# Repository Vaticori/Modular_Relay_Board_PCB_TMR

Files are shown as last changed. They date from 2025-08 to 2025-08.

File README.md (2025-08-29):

# Modular Relay Board TMR
A 4 channel relay board made for the Toronto Metropolitan Robotics team for higher voltage inputs to be switched using the onboard Teensy 4.1 MCU. 
I have linked the 3D model below, and a high resolution pdf of the schematic can be found in the repository. 

# [View Interactive 3D Model of my PCB!](https://skfb.ly/pACNG)
 
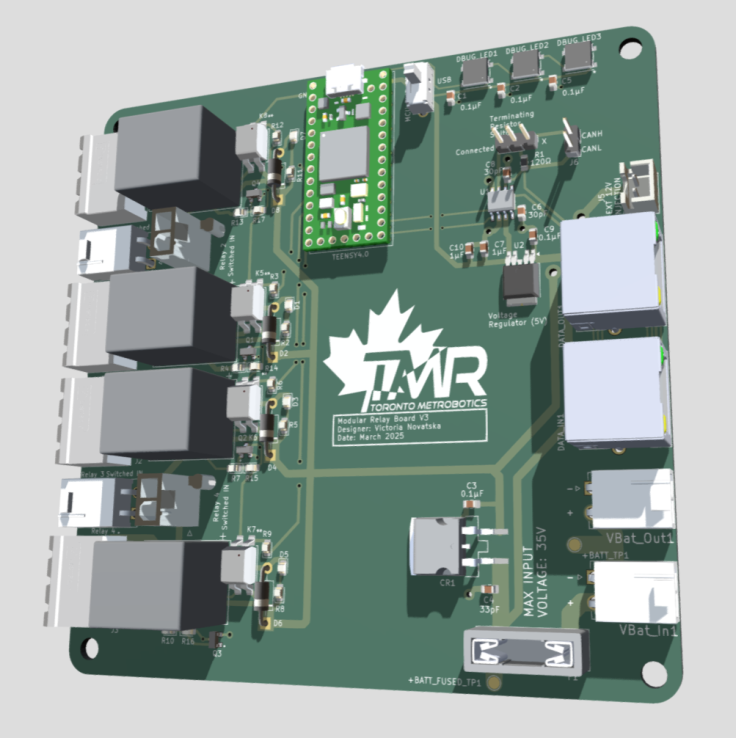
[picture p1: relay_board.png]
Relay Board


## Schematic 
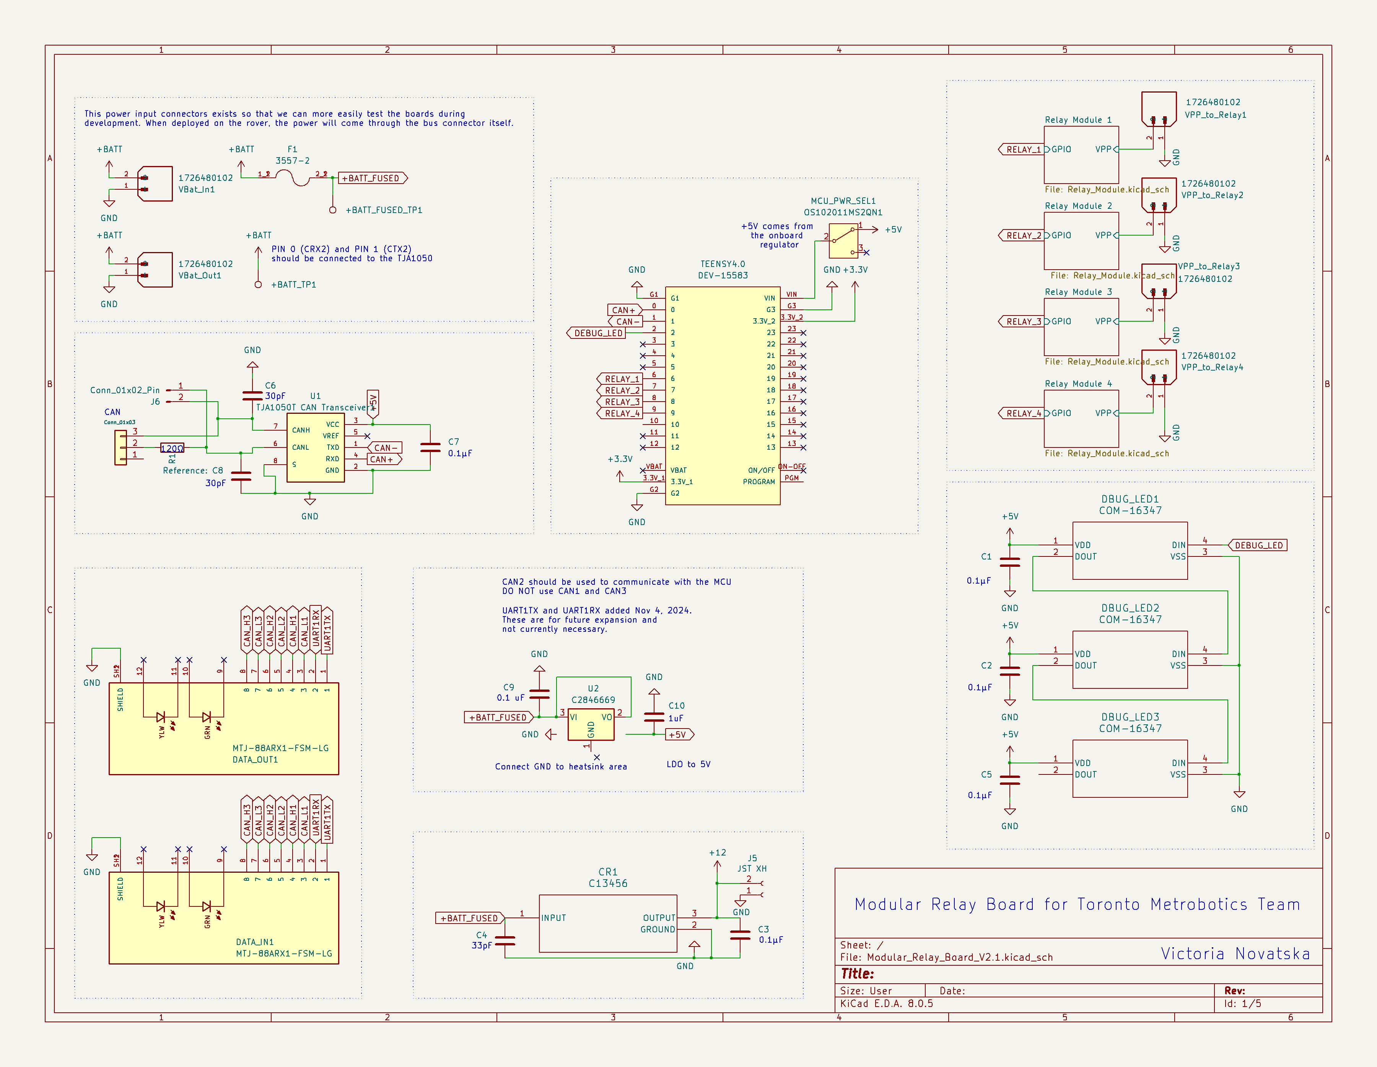
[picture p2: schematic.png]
Schematic


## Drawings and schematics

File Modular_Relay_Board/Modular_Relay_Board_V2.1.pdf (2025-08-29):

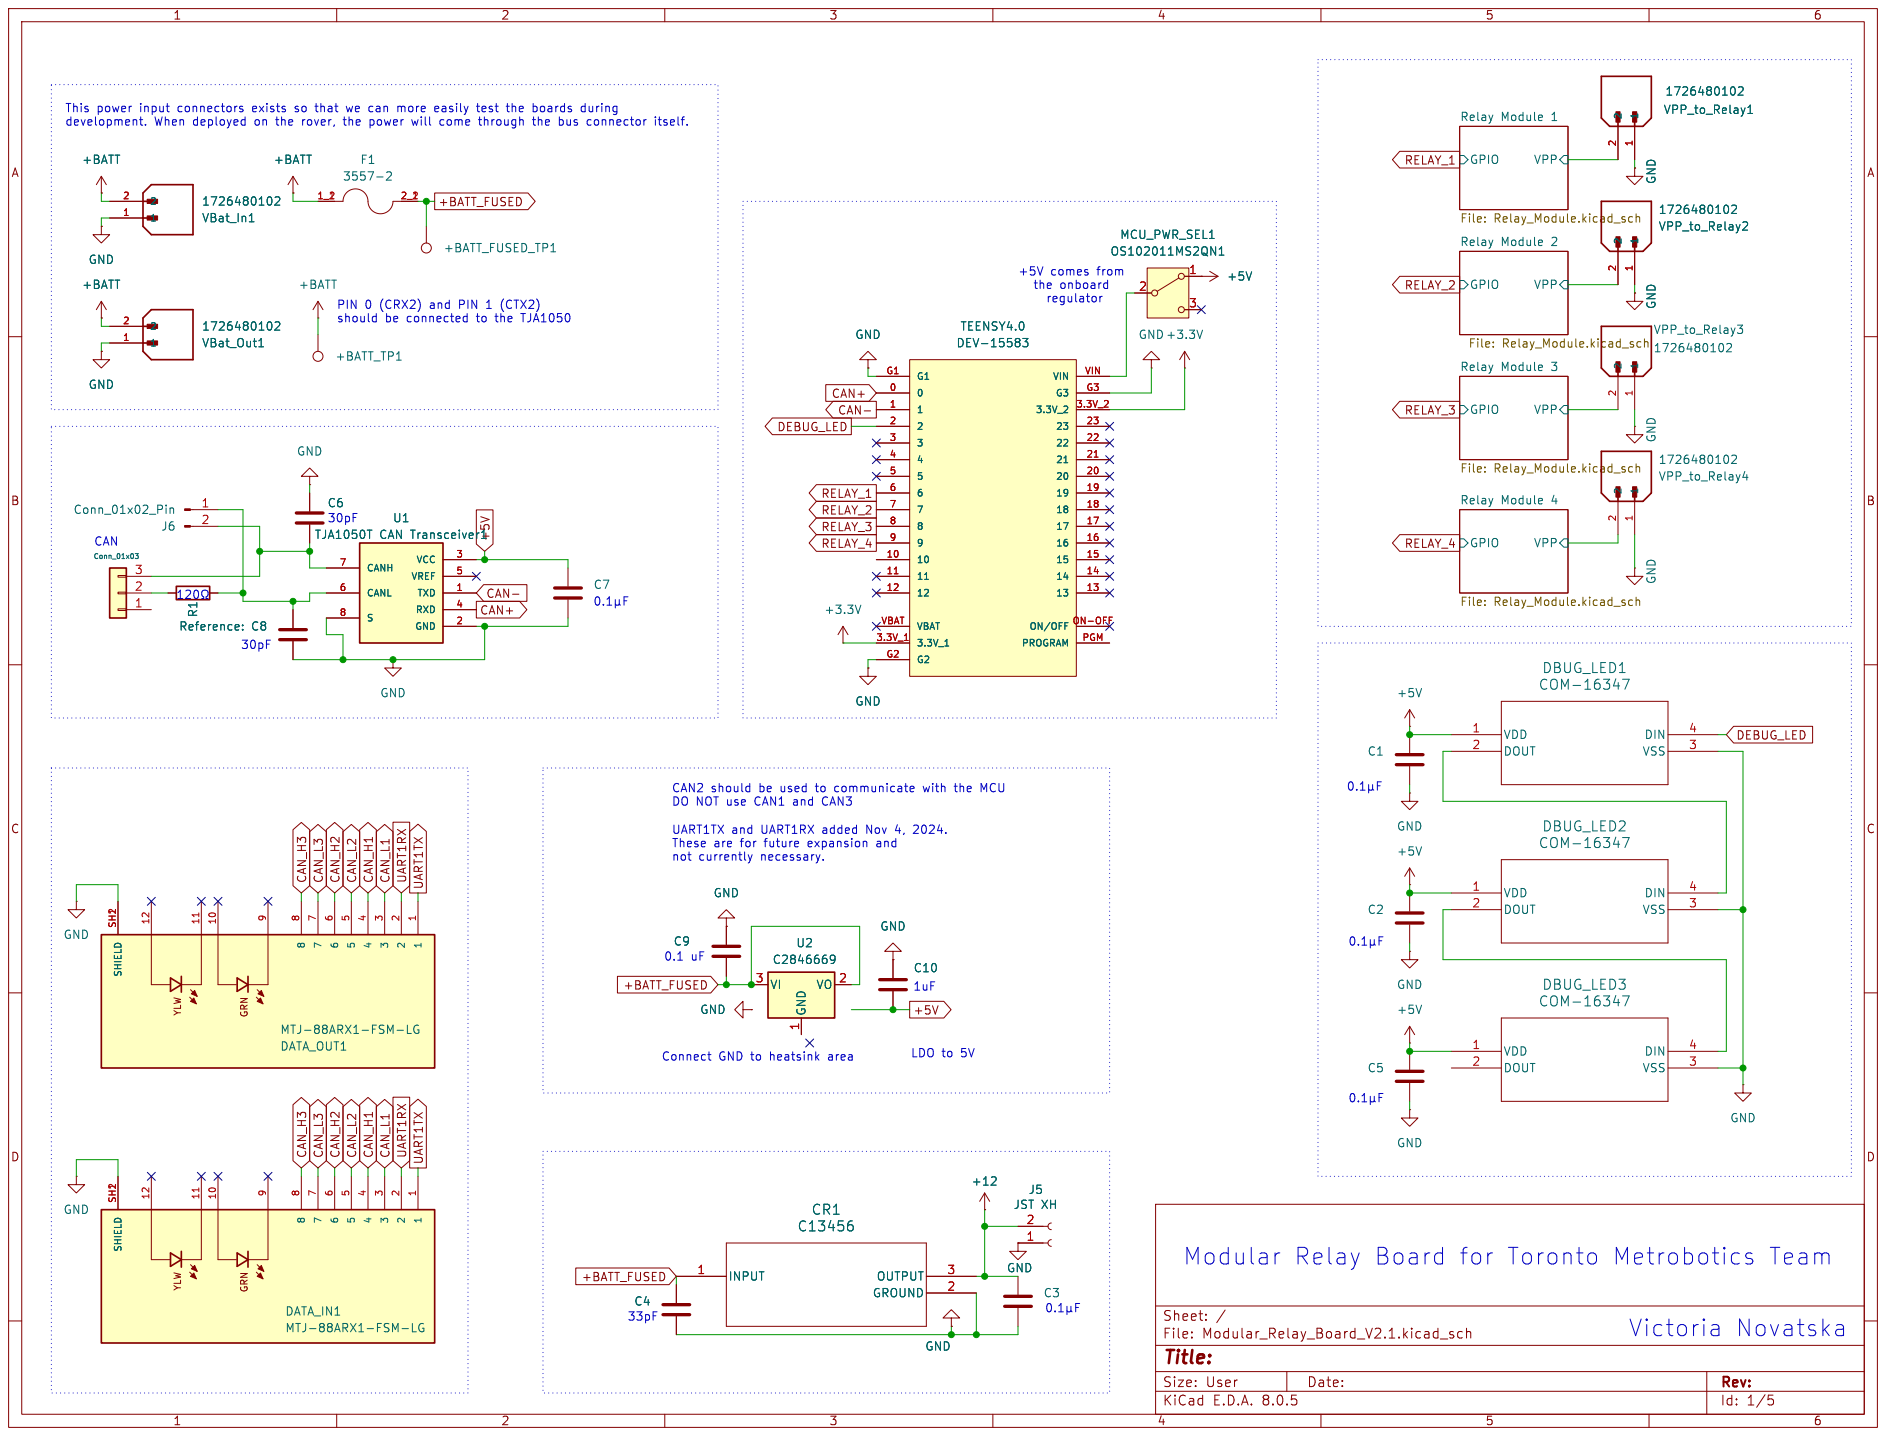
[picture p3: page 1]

DO NOT use CAN1 and CAN3 CAN

8 SHIELD SH12 DATA_OUT1 MTJ-88ARX1-FSM-LG

8 SHIELD SH12 DATA_IN1 MTJ-88ARX1-FSM-LG

Id: 1/5 Title: File: Modular_Relay_Board_V2.1.kicad_sch Sheet: /

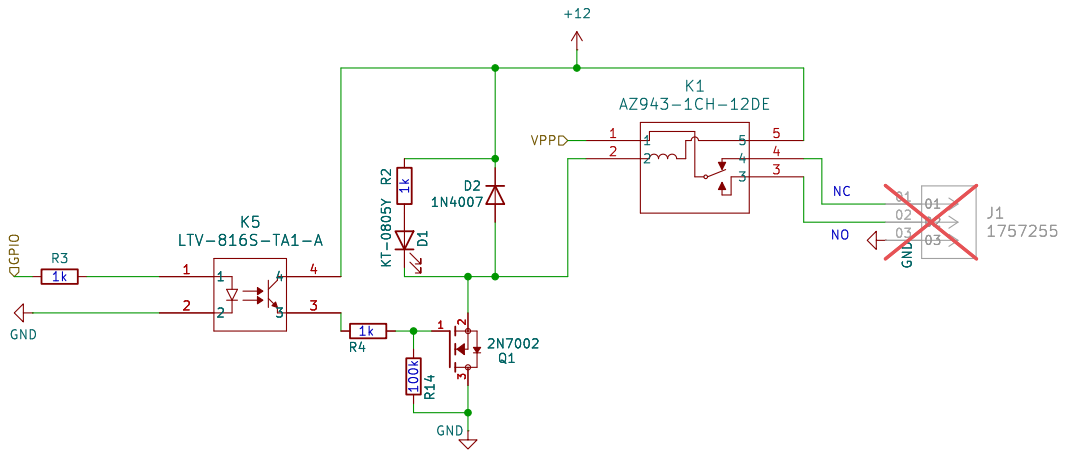
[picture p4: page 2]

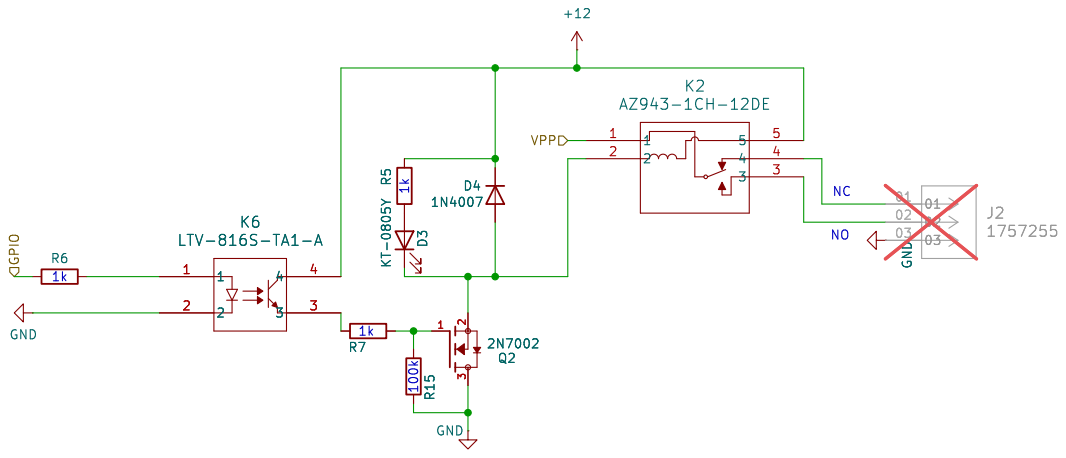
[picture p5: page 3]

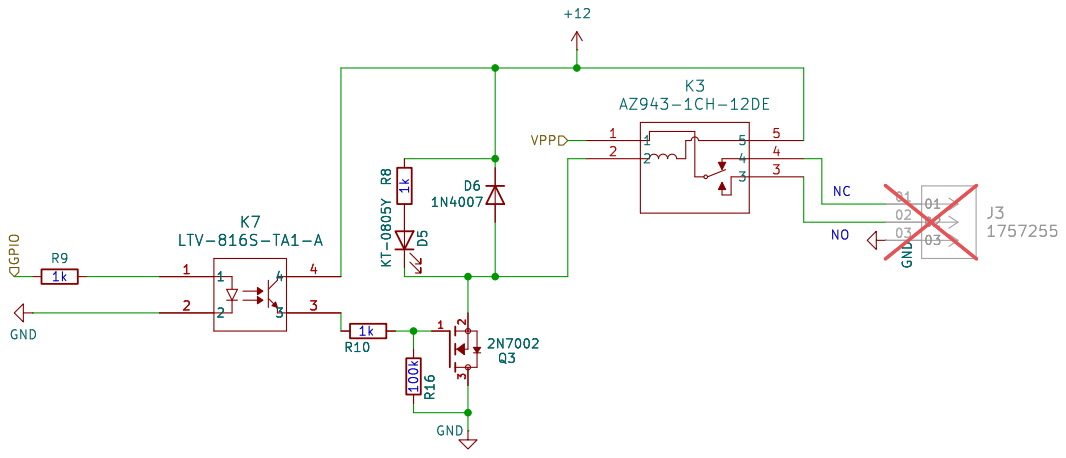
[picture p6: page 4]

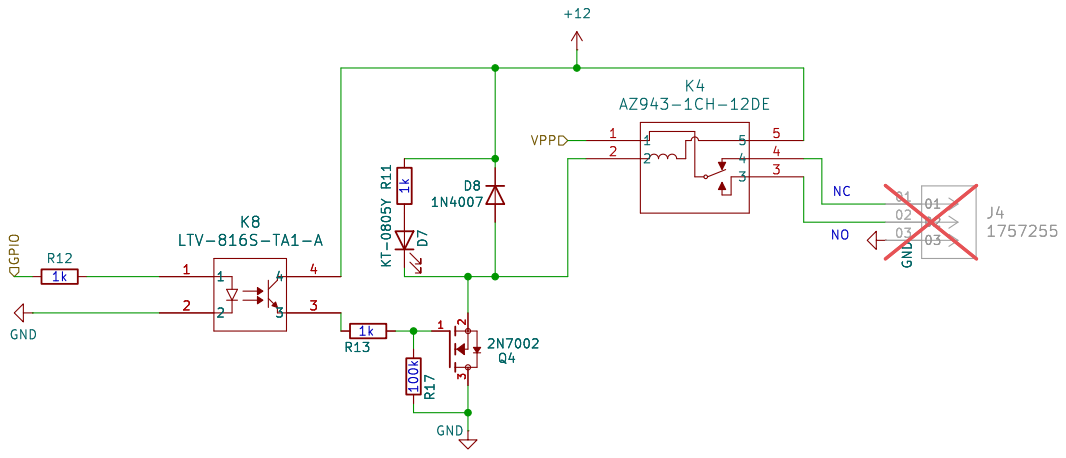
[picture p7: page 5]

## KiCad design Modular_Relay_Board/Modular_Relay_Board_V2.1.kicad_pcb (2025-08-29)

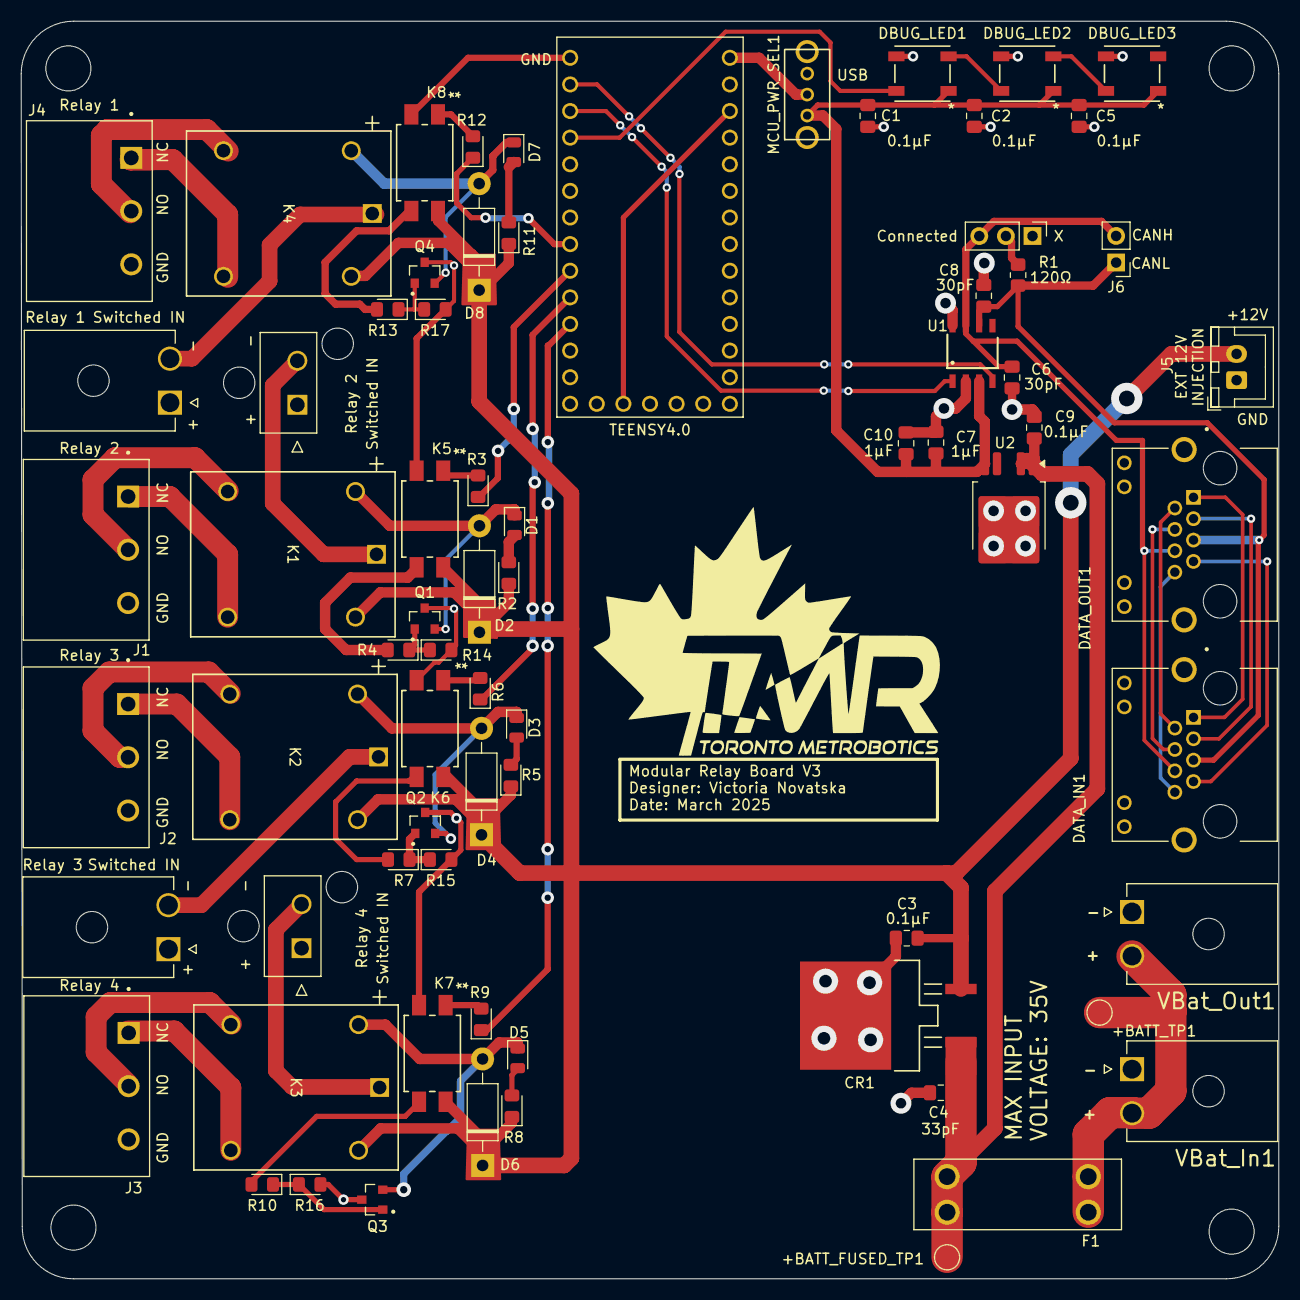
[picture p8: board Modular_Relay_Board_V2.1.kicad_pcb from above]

Board: 2 copper layers, 120.0 x 120.0 mm, 73 parts (0 on the bottom side), 57 nets.

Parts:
+BATT_FUSED_TP1: TestPoint; TestPoint_Pad_D2.0mm
+BATT_TP1: TestPoint; TestPoint_Pad_D2.0mm
C1, C2, C3, C5, C7, C9: CL21B104KBCNNNC; C_0805_2012Metric_Pad1.18x1.45mm_HandSolder
C4: CC0805JRNPO9BN330; C_0805_2012Metric_Pad1.18x1.45mm_HandSolder
C6, C8: 0805CG300J500NT; C_0805_2012Metric_Pad1.18x1.45mm_HandSolder
C10: CL21B105KAFNFNE; C_0805_2012Metric_Pad1.18x1.45mm_HandSolder
CR1: C13456; D2PAK_STM
D1, D3, D5, D7: KT-0805Y; LED_0805_2012Metric
D2, D4, D6, D8: 1N4007; D_DO-41_SOD81_P10.16mm_Horizontal
DATA_IN1: MTJ-88ARX1-FSM-LG; ADAMTECH_MTJ-88ARX1-FSM-LG
DATA_OUT1: MTJ-88ARX1-FSM-LG; ADAMTECH_MTJ-88ARX1-FSM-LG
DBUG_LED1, DBUG_LED2, DBUG_LED3: COM-16347; COM-16347_SPK-M
F1: 3557-2; FUSE_3557-2
J1, J2, J3, J4: 1757255; PHOENIX_1757255
J5: JST XH; JST_XH_B2B-XH-A_1x02_P2.50mm_Vertical
J6: Conn_01x02_Pin; PinHeader_1x02_P2.54mm_Vertical
K1, K2, K3, K4: AZ943-1CH-12DE; AZ943-1CH_AMZ
K5, K6, K7, K8: LTV-816S-TA1-A; LTV-816S_LTO
MCU_PWR_SEL1: OS102011MS2QN1
Q1, Q2, Q3, Q4: 2N7002; TRANS_2N7002
R1: 0805W8F1200T5E; R_0805_2012Metric_Pad1.20x1.40mm_HandSolder
R2, R3, R4, R5, R6, R7, R8, R9, R10, R11, R12, R13: 0805W8F1001T5E; LED_0805_2012Metric_Pad1.15x1.40mm_HandSolder
R14, R15, R16, R17: 0805W8F1003T5E (SMT业务专用); LED_0805_2012Metric_Pad1.15x1.40mm_HandSolder
TEENSY4.0: DEV-15583; MODULE_DEV-15583
TerminatingResistorSwitch1: Conn_01x03; PinHeader_1x03_P2.54mm_Vertical
U1: TJA1050T CAN Transceiver1; SOT96-1
U2: C2846669; TO-252-4
VBat_In1: 1726480102; MOLEX_1726480102
VBat_Out1: 1726480102; MOLEX_1726480102
VPP_to_Relay1, VPP_to_Relay3: 1726480102; MOLEX_1726480102
VPP_to_Relay2, VPP_to_Relay4: 1726480102; 172647-0102

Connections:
+3.3V: TEENSY4.0.3.3V_1, TEENSY4.0.3.3V_2
+5V: C1.1, C2.1, C5.1, C7.1, C10.1, DBUG_LED1.1 (VDD), DBUG_LED2.1 (VDD), DBUG_LED3.1 (VDD), MCU_PWR_SEL1.1 (A), U1.3 (VCC), U2.5 (Q)
+12: C3.2, CR1.3 (OUTPUT), D2.1 (K), D4.1 (K), D6.1 (K), D8.1 (K), J5.2, K1.5, K2.5, K3.5, K4.5, K5.4, K6.4, K7.4, K8.4, R2.1, R5.1, R8.1, R11.1
+BATT: +BATT_TP1.1, F1.1_1, F1.1_2, VBat_In1.2, VBat_Out1.2
+BATT_FUSED: +BATT_FUSED_TP1.1, C4.1, C9.1, CR1.1 (INPUT), F1.2_1, F1.2_2, U2.1 (VI), U2.2 (EN)
/Relay Module 1/VPP: K4.1, VPP_to_Relay1.2
/Relay Module 2/VPP: K1.1, VPP_to_Relay2.2
/Relay Module 3/VPP: K2.1, VPP_to_Relay3.2
/Relay Module 4/VPP: K3.1, VPP_to_Relay4.2
CAN+: TEENSY4.0.0, U1.4 (RXD)
CAN-: TEENSY4.0.1, U1.1 (TXD)
CAN_H1: DATA_IN1.4, DATA_OUT1.4
CAN_H2: C6.1, DATA_IN1.6, DATA_OUT1.6, J6.2, TerminatingResistorSwitch1.3, U1.7 (CANH)
CAN_H3: DATA_IN1.8, DATA_OUT1.8
CAN_L1: DATA_IN1.3, DATA_OUT1.3
CAN_L2: C8.1, DATA_IN1.5, DATA_OUT1.5, J6.1, R1.1, U1.6 (CANL)
CAN_L3: DATA_IN1.7, DATA_OUT1.7
DEBUG_LED: DBUG_LED1.4 (DIN), TEENSY4.0.2
GND: C1.2, C2.2, C3.1, C4.2, C5.2, C6.2, C7.2, C8.2, C9.2, C10.2, CR1.2 (GROUND), DATA_IN1.SH1 (SHIELD), DATA_IN1.SH2 (SHIELD), DATA_OUT1.SH1 (SHIELD), DATA_OUT1.SH2 (SHIELD), DBUG_LED1.3 (VSS), DBUG_LED2.3 (VSS), DBUG_LED3.3 (VSS), J1.03, J2.03, J3.03, J4.03, J5.1, K5.2, K6.2, K7.2, K8.2, Q1.3, Q2.3, Q3.3, Q4.3, R14.2, R15.2, R16.2, R17.2, TEENSY4.0.G1, TEENSY4.0.G2, TEENSY4.0.G3, U1.2 (GND), U1.8 (S), U2.3 (GND), VBat_In1.1, VBat_Out1.1, VPP_to_Relay1.1, VPP_to_Relay2.1, VPP_to_Relay3.1, VPP_to_Relay4.1
unnamed: D1.2 (A), R2.2
unnamed: D1.1 (K), D2.2 (A), K1.2, Q1.2
unnamed: D3.2 (A), R5.2
unnamed: D3.1 (K), D4.2 (A), K2.2, Q2.2
unnamed: D5.2 (A), R8.2
unnamed: D5.1 (K), D6.2 (A), K3.2, Q3.2
unnamed: D7.2 (A), R11.2
unnamed: D7.1 (K), D8.2 (A), K4.2, Q4.2
unnamed: DBUG_LED1.2 (DOUT), DBUG_LED2.4 (DIN)
unnamed: DBUG_LED2.2 (DOUT), DBUG_LED3.4 (DIN)
unnamed: J1.01, K1.4
unnamed: J1.02, K1.3
unnamed: J2.01, K2.4
unnamed: J2.02, K2.3
unnamed: J3.01, K3.4
unnamed: J3.02, K3.3
unnamed: J4.01, K4.4
unnamed: J4.02, K4.3
unnamed: K5.1, R3.2
unnamed: K5.3, R4.2
unnamed: K6.1, R6.2
unnamed: K6.3, R7.2
unnamed: K7.1, R9.2
unnamed: K7.3, R10.2
unnamed: K8.1, R12.2
unnamed: K8.3, R13.2
unnamed: MCU_PWR_SEL1.2 (B), TEENSY4.0.VIN
unnamed: Q1.1, R4.1, R14.1
unnamed: Q2.1, R7.1, R15.1
unnamed: Q3.1, R10.1, R16.1
unnamed: Q4.1, R13.1, R17.1
unnamed: R1.2, TerminatingResistorSwitch1.2
RELAY_1: R12.1, TEENSY4.0.6
RELAY_2: R3.1, TEENSY4.0.7
RELAY_3: R6.1, TEENSY4.0.8
RELAY_4: R9.1, TEENSY4.0.9
UART1RX: DATA_IN1.2, DATA_OUT1.2
UART1TX: DATA_IN1.1, DATA_OUT1.1
